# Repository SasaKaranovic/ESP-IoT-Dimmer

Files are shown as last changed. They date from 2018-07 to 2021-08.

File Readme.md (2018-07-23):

# ESP IoT Dimmer

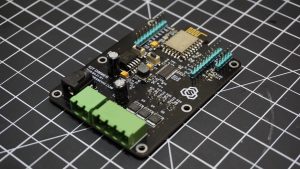
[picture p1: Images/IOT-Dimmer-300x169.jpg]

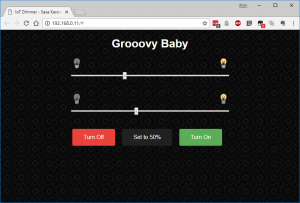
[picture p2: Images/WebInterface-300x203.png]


Making a IoT LED dimmer that you can control through your PC, your mobile, tablet or any other device connected to the network is super simple, and I'm going to show you how.

In this project I'm making a three channel LED dimmer that you can use to dim single RGB LED strip or dim three separate LED channels. I want to be able to control lights above my desk and also mix warm white and cool white strip to give me more flexibility over lighting while I'm working, taking pictures or watching movies.

This is going to be a very short and very simple project that if you follow steps below, you can build it in an hour (excluding lead time for components).

[Project home page](https://sasakaranovic.com/projects/iot-led-dimmer/)

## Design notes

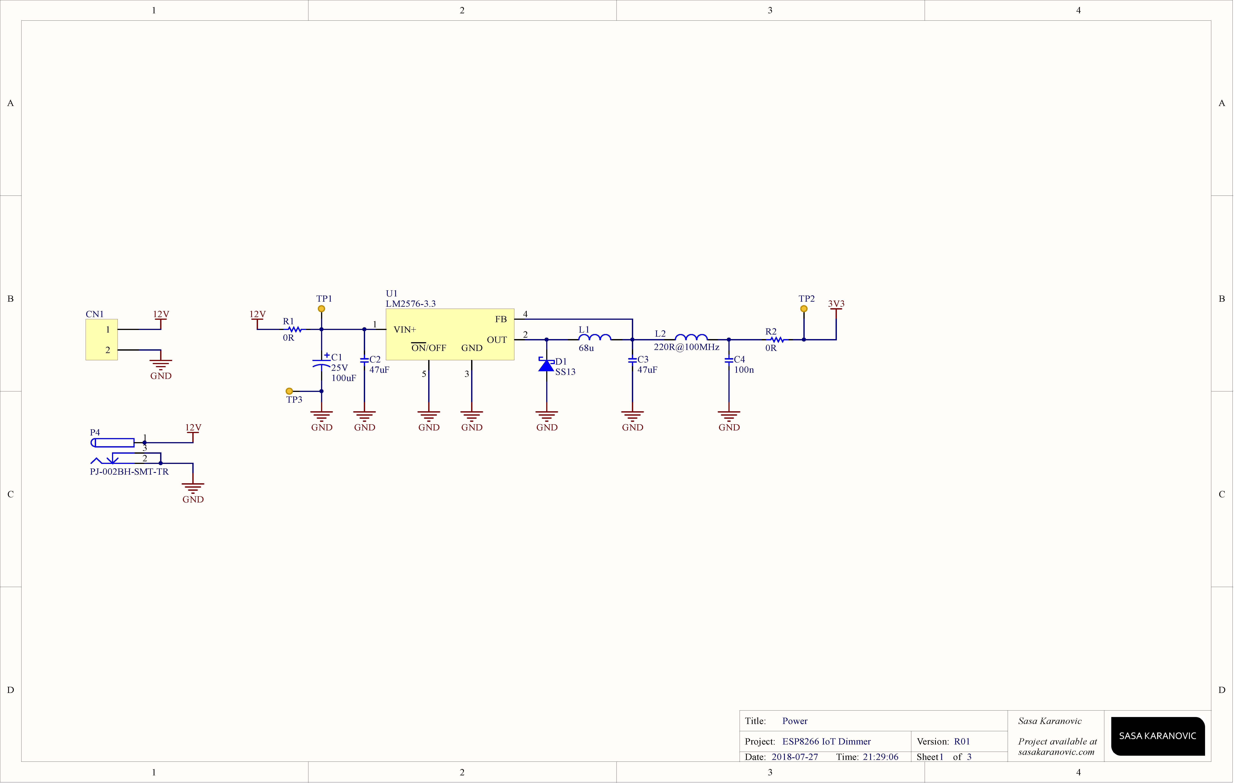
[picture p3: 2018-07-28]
Schematic/IoT Dimmer Schematic_Page_3.jpg

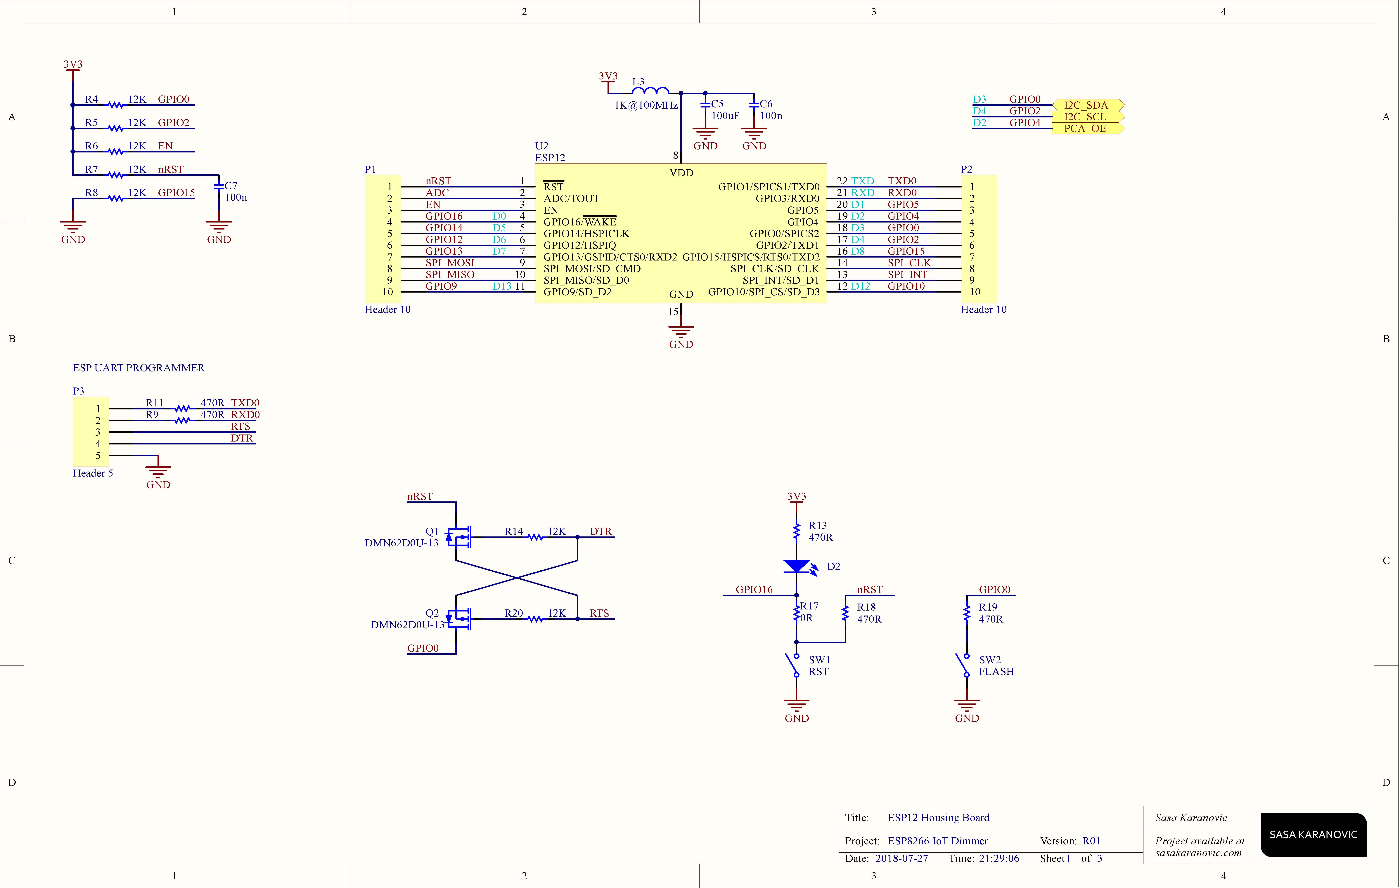
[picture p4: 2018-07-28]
Schematic/IoT Dimmer Schematic_Page_2.jpg

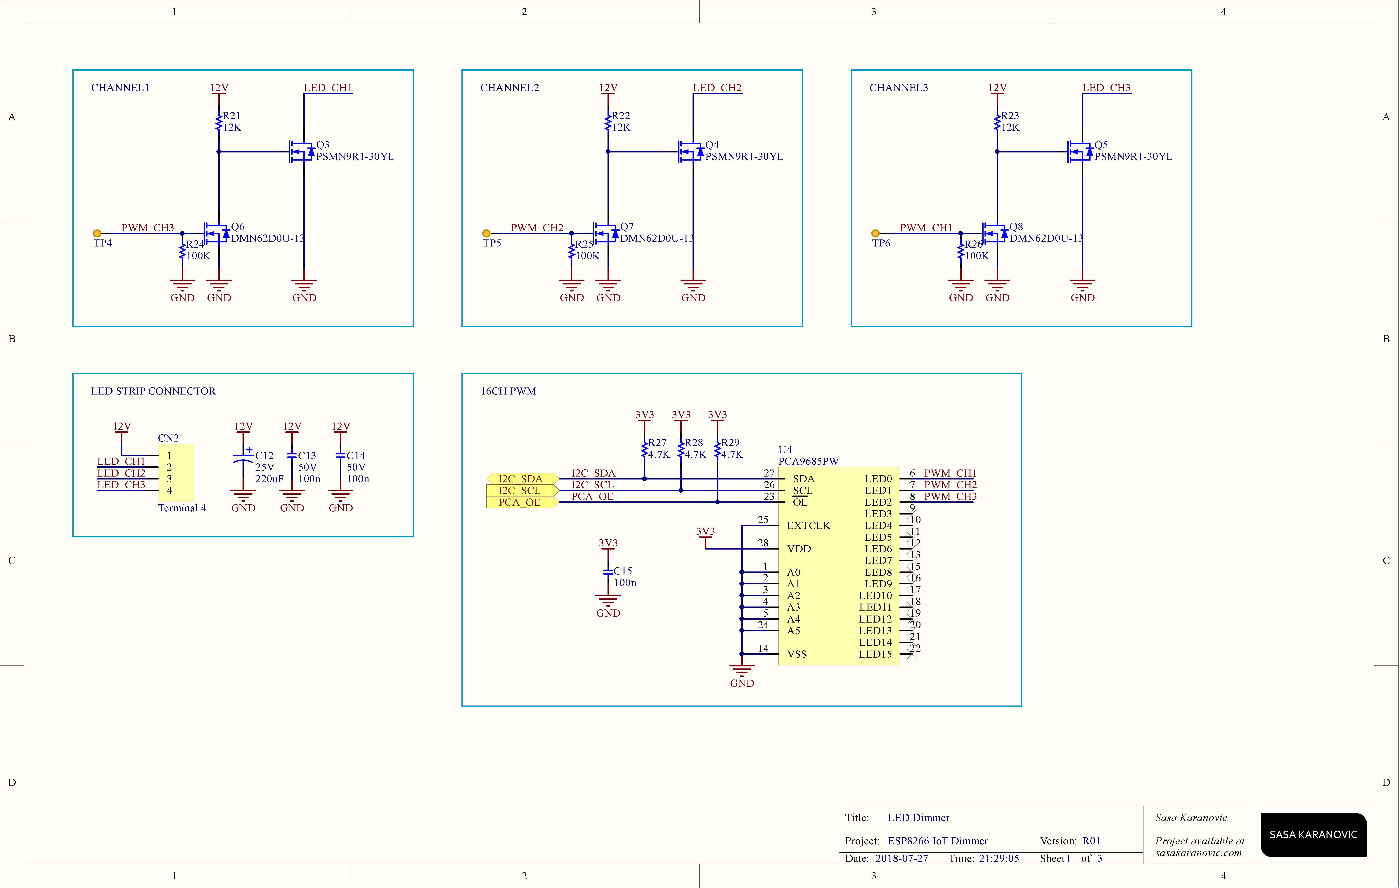
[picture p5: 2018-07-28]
Schematic/IoT Dimmer Schematic_Page_1.jpg

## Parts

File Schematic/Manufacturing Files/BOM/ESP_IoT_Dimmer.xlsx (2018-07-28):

Designator | Description | Manufacturer | Manufacturer Part Number | Quantity
C1 | CAP ALUM 100UF 20% 25V RADIAL | Nichicon | UHE1E101MED | 1
C2, C3 | CAP TANT POLY47UF 20% 16V 1210 | AVX Corporation | TCNT476M016R0200A | 2
C4, C6, C7, C13, C14, C15 | Capacitor | AVX Corporation | 06035C104KAT2A | 6
C5 | Capacitor | AVX Corporation | TAJB107M006RNJ | 1
C12, R9, R11, R13, R18, R19 | Polarized Capacitor (Axial), Resistor, Resistor, Resistor, Resistor, Resistor | Yageo | AC0603FR-07470RL | 6
CN1 | TERM BLOCK PCB 2POS 5.0MM GREEN | Phoenix Contact | 1935161 | 1
CN2 | TERM BLOCK PCB 4POS 5.0MM GREEN | Phoenix Contact | 1935187 | 1
D1 | DIODE SCHOTTKY 30V 1A SMA | ON Semiconductor | SS13 | 1
D2 | Typical RED GaAs LED | Lite-On Inc. | LTST-C193KRKT-5A | 1
L1 | FIXED IND 68UH 1A 289 MOHM SMD | Laird-Signal Integrity Products | TYS6045680M-10 | 1
L2 | FERRITE BEAD 220 OHM 0603 1LN | Murata Electronics North America | BLM18KG221SN1D | 1
L3 | FERRITE BEAD 1 KOHM 0603 1LN | TDK Corporation | MPZ1608S102ATA00 | 1
P1, P2, SW1, SW2 | Header, 10-Pin, Header, 10-Pin, Switch, Switch | Harwin Inc. | M20-9991046 | 4
P3 | SIL VERTICAL PC TAIL PIN HEADER | Harwin Inc. | M20-9990546 | 1
P4 | CONN PWR JACK 2.5X5.5MM SOLDER | CUI Inc. | PJ-002BH-SMT-TR | 1
Q1, Q2, Q6, Q7, Q8 | MOSFET N-CH 60V 0.38A | Diodes Incorporated | DMN62D0U-13 | 5
Q3, Q4, Q5 | MOSFET N-CH 30V 37A LFPAK | Nexperia USA Inc. | PSMN011-30YLC,115 | 3
R1, R2, R17 | Resistor | Yageo | RC0603JR-070RL | 3
R4, R5, R6, R7, R8, R14, R20, R21, R22, R23 | Resistor | Yageo | RT0603FRE0712KL | 10
R24, R25, R26 | Resistor | Yageo | RT0603BRD07100KL | 3
R27, R28, R29 | Resistor | Yageo | RT0603FRE074K7L | 3
U1 | Switching mode regulator [ 3v3, 5v, 12v and ADJ ] | Microchip Technology | LM2576-3.3WU | 1
U2 | ESP8266 SMT Module - ESP-12S | Seeed Technology Co., Ltd | 317060015 | 1
U4 | IC LED DRIVER RGBA 28-TSSOP | NXP USA Inc. | PCA9685PW,118 | 1
* Note
Manufacturer Part Number is for your reference only. I already had most of the components in stock so I used the ones I have handy. You may also replace any component with the one you have laying around.

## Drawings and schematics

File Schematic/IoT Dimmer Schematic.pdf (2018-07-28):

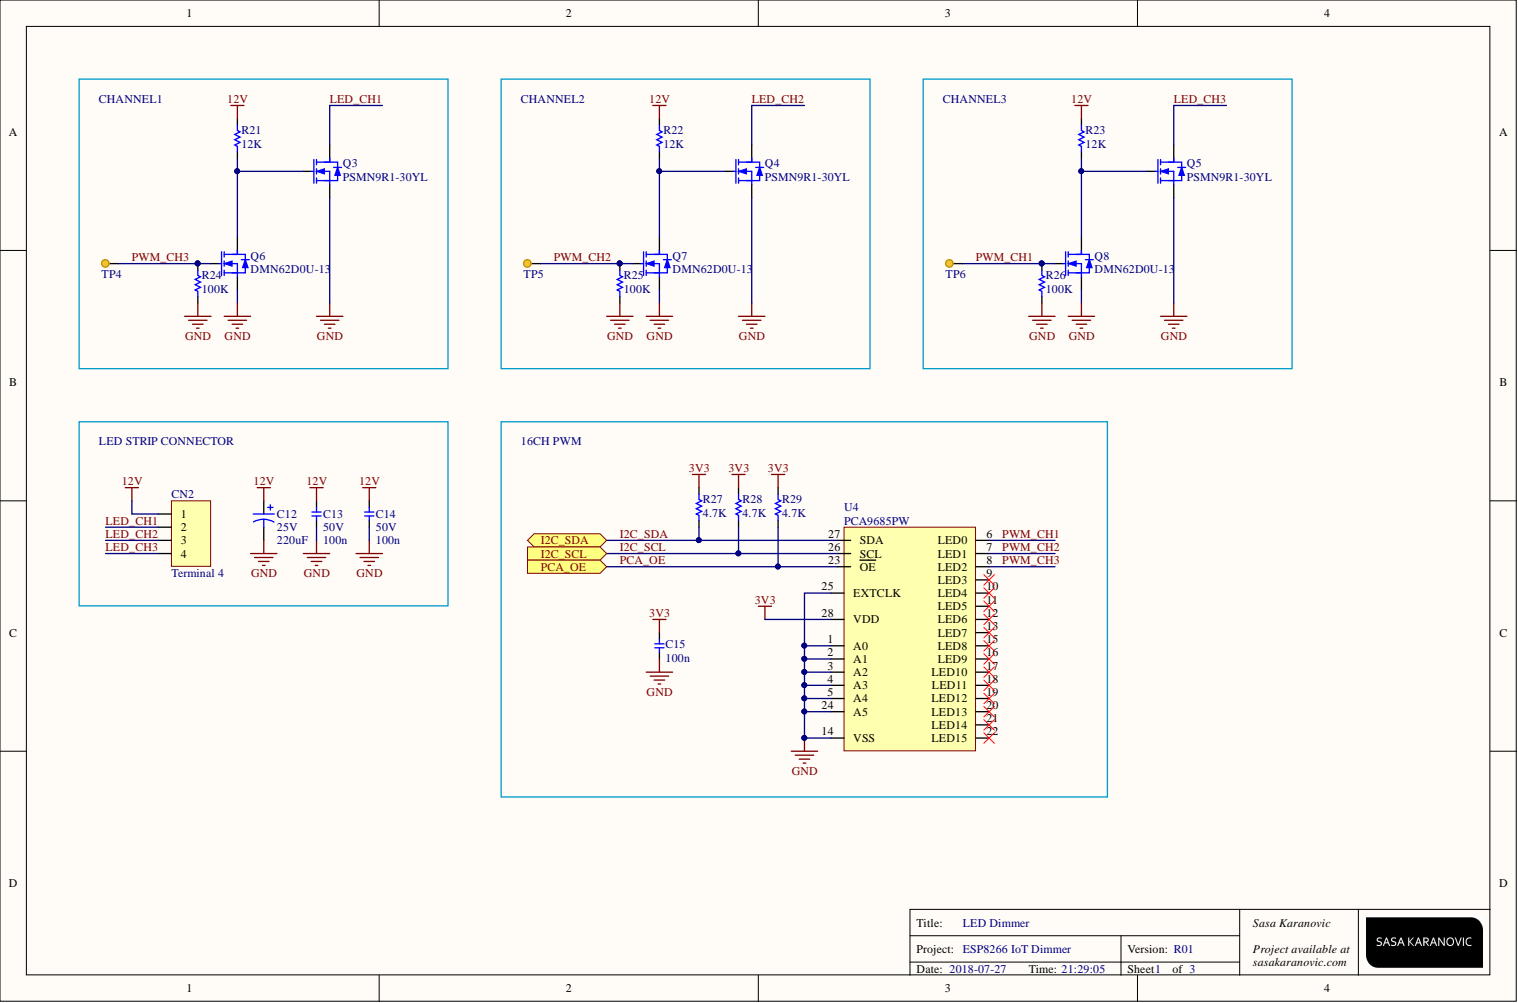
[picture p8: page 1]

VDD 28

A0 1
A1 2
A2 3
A3 4
A4 5
A5 24

VSS 14

Title: LED Dimmer | Sasa Karanovic Project available at sasakaranovic.com

Project: ESP8266 IoT Dimmer | Version: R01
Date: Time: 2018-07-27 21:29:05 | Sheet of 1 3

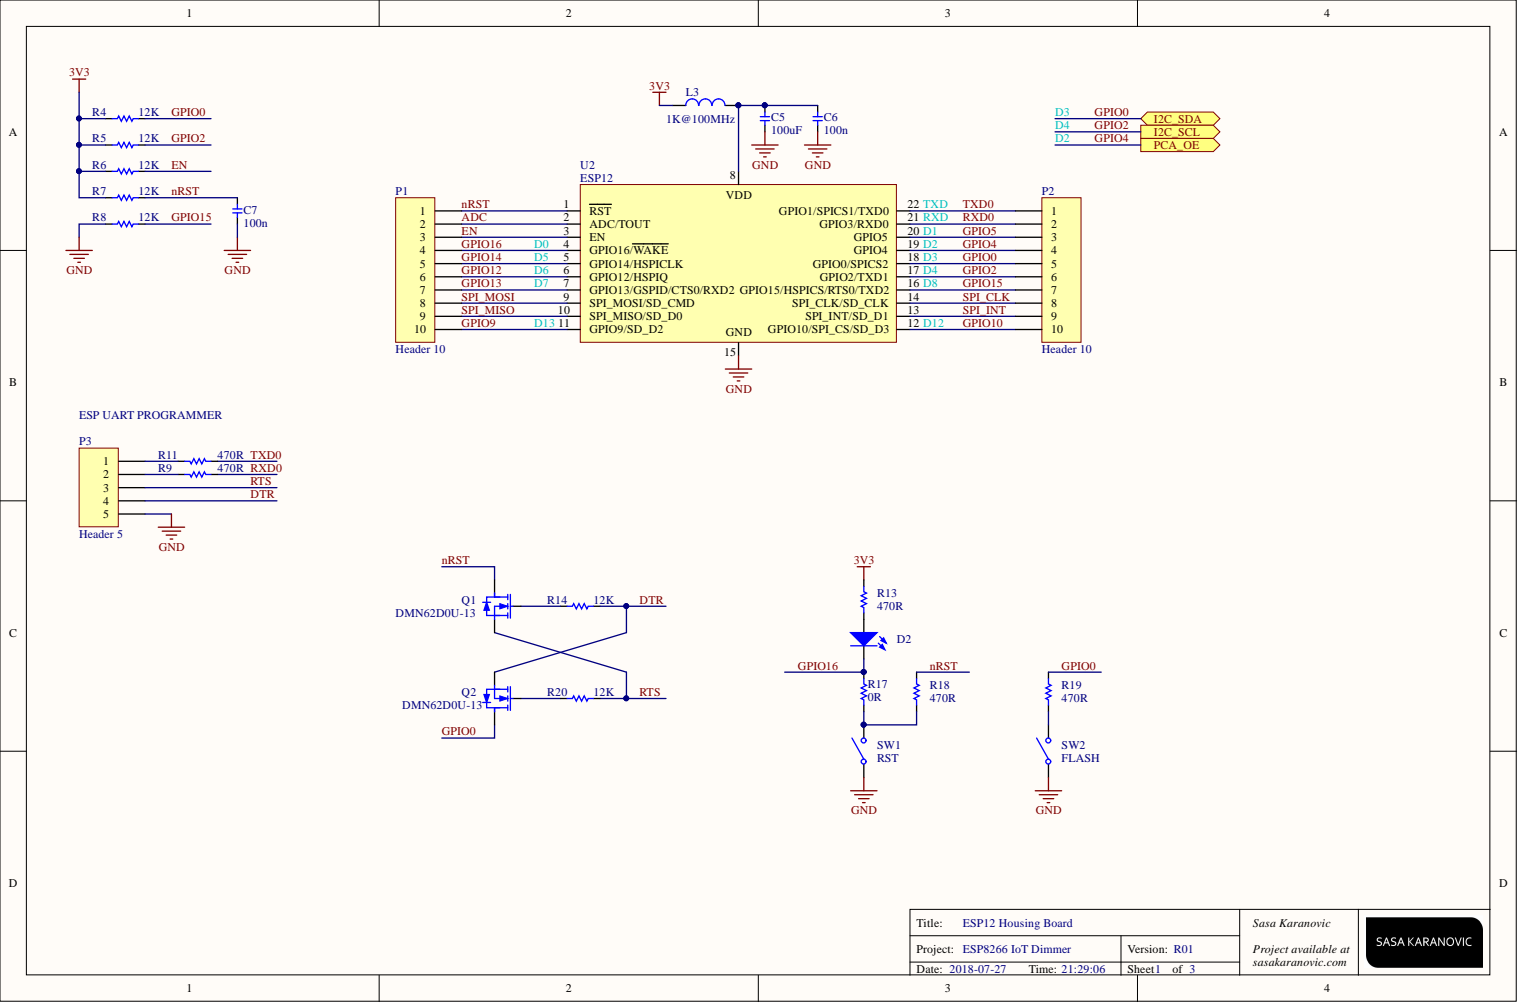
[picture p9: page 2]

GPIO16 D0 | GPIO16/WAKE 4 | D2 GPIO4
GPIO14 D5 | GPIO14/HSPICLK 5 | D3 GPIO0
GPIO12 D6 | GPIO12/HSPIQ 6 | D4 GPIO2
GPIO13 D7 | GPIO13/GSPID/CTS0/RXD2 7 | D8 GPIO15
SPI_MOSI | SPI_MOSI/SD_CMD 9 | SPI_CLK

Title: ESP12 Housing Board | Sasa Karanovic Project available at sasakaranovic.com

Project: ESP8266 IoT Dimmer | Version: R01
Date: Time: 2018-07-27 21:29:06 | Sheet of 1 3

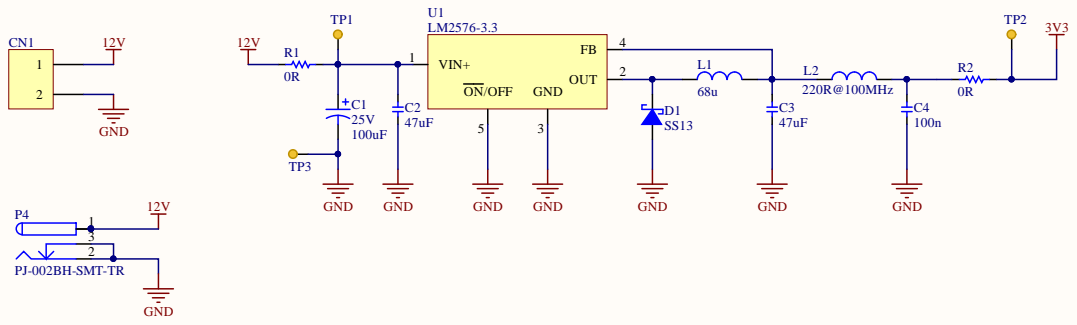
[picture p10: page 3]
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

Project : ESP8 6 Io T D immer | Vers i o n : R0
Date: 8-0 7-2 T ime: : : | Sheet o f

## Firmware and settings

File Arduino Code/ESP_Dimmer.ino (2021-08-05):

#include <ESP8266WiFi.h>
#include <ESP8266WiFiMulti.h>
#include <WebSocketsServer.h>
#include <Hash.h>
#include <String.h>
#include <ESP8266WebServer.h>
#include <ESP8266mDNS.h>
#include <Wire.h>
#include <Adafruit_PWMServoDriver.h>
// called this way, it uses the default address 0x40
Adafruit_PWMServoDriver pwm = Adafruit_PWMServoDriver();

// WiFi Configuration (hard-coded at the moment)
// static const char ssid[] = "__Your-WiFi-SSID__";
// static const char password[] = "__Your-WiFi-Password-Here__";

// mDNS hostname for this device
// You should be able to call http://dimmer.iot
static const char dns_hostname[] = "dimmer";

// Channel Configuration (pins)
#define CH1_PIN         0
#define CH2_PIN         1
#define CH3_PIN         2
#define EN_PIN          4

#define DEBUG_BUILD 0

// Global variables
volatile uint32_t milis_update = 0;
volatile uint32_t debug_update = 0;
volatile uint16_t ch1_target   = 0;  // Channel target value (not used yet)
volatile uint16_t ch2_target   = 0;  // Channel target value (not used yet)
volatile uint16_t ch3_target   = 0;  // Channel target value (not used yet)

// GPIO#0 is for Adafruit ESP8266 HUZZAH board. Your board LED might be on 13.
const int LEDPIN = 0;

// Static function definitions
static void writeLED(uint8_t channel, uint16_t value);

// Initialize classes
MDNSResponder mdns;
ESP8266WiFiMulti WiFiMulti;
ESP8266WebServer server(80);
WebSocketsServer webSocket = WebSocketsServer(81);

// -- BEGIN Index.html
static const char PROGMEM INDEX_HTML[] = R"rawliteral(
<!DOCTYPE html>
<html>
<head>
<meta name = "viewport" content = "width = device-width, initial-scale = 1.0, maximum-scale = 1.0, user-scalable=0">
<title>Sasa's IoT Dimmer - Sasa Karanovic</title>
<style>
body { background: #262830 url('http://sasakaranovic.com/iotdimmer/bg.png') repeat; font-family: Arial, Helvetica, Sans-Serif; Color: #fffff9; }
#container { width: 80%; max-width: 450px; margin: auto; }
.bulb { display: block; clear: none; width: 32px; height: 32px; padding-bottom: 0.5em; background-attachment: fixed; background-position: center; background-repeat: no-repeat; }
.bulbOn { background: transparent url('http://sasakaranovic.com/iotdimmer/bulbON.png') top left no-repeat; float: right; }
.bulbOff{ background: transparent url('http://sasakaranovic.com/iotdimmer/bulbOFF.png') top left no-repeat; float: left; }
h1 {  display: block; font-size: 2em; margin-top: 0.67em; margin-bottom: 0.67em; margin-left: 0; margin-right: 0; font-weight: bold; text-align: center; }
.slidecontainer {width: 100%; }
.slider {width: 100%; margin: 0 0 3em 0; }
  .buttonOff { background-color: #f44336; }
  .buttonOn{ background-color: #4CAF50; }
  a { 
  background-color: #212121;
    border: none;
    color: white;
    padding: 15px 32px;
  margin-right: 1em;
    text-align: center;
    text-decoration: none;
    display: inline-block;
    font-size: 16px;
  border-radius: 4px;
  }
</style>
<script>
var websock;
function start() {
websock = new WebSocket('ws://' + window.location.hostname + ':81/');
websock.onopen = function(evt) { console.log('websock open'); };
websock.onclose = function(evt) { console.log('websock close'); };
websock.onerror = function(evt) { console.log(evt); };
websock.onmessage = function(evt) {
console.log(evt);
var ch1 = document.getElementById('ch1');
var ch2 = document.getElementById('ch2');
var ch3 = document.getElementById('ch3');
var ch_values = JSON.parse(evt.data);
ch1.value = ch_values.ch1;
ch2.value = ch_values.ch2;
ch3.value = ch_values.ch3;
};
}
function setAll(val) {
var dat = 'ch0:'+ val
websock.send(dat);
}
function updateSlider(e) {
var dat = e.id +':'+ e.value
websock.send(dat);
}
</script>
</head>
<body onload="javascript:start();">
<div id="container">
<h1>Grooovy Baby</h1>
<div class="slidecontainer">
<div class="bulb bulbOn"></div>
<div class="bulb bulbOff"></div>
<input id="ch1" type="range" min="1" max="4095" value="0" class="slider" onchange="updateSlider(this)">
</div>
<div class="slidecontainer">
<div class="bulb bulbOn"></div>
<div class="bulb bulbOff"></div>
<input id="ch2" type="range" min="1" max="4095" value="0" class="slider" onchange="updateSlider(this)">
</div>
<div class="slidecontainer" style="display:none; visibility: hidden">
<div class="bulb bulbOn"></div>
<div class="bulb bulbOff"></div>
<input id="ch3" type="range" min="1" max="4095" value="0" class="slider" onchange="updateSlider(this)">
</div>
<div class="slidecontainer" style="text-align: center">
<a href="#" class="buttonOff" onClick="setAll(1)">Turn Off</a> <a href="#" onClick="setAll(2049)">Set to 50%</a> <a href="#" class="buttonOn"  onClick="setAll(4096)">Turn On</a>
</div>
</div>
</body>
</html>
)rawliteral";
// -- END Index.html

// WebSocket Event Handler
void webSocketEvent(uint8_t num, WStype_t type, uint8_t * payload, size_t length)
{
  char buffer[40] = {0};
  String content((char*)payload);
  #if DEBUG_BUILD
  Serial.printf("webSocketEvent(%d, %d, ...)\r\n", num, type);
  #endif
  switch(type) {
    case WStype_DISCONNECTED:
      Serial.printf("[%u] Disconnected!\r\n", num);
      break;
    // --When new connection is established
    case WStype_CONNECTED:
      {
        IPAddress ip = webSocket.remoteIP(num);
        sprintf(buffer, "{\"ch1\":%d,\"ch2\":%d,\"ch3\":%d}", ch1_target,  ch2_target,  ch3_target);
        #if DEBUG_BUILD
        Serial.printf("[%u] Connected from %d.%d.%d.%d url: %s\r\n", num, ip[0], ip[1], ip[2], ip[3], payload);
        #endif
        // Send the current LED status
        webSocket.sendTXT(num, buffer, strlen(buffer));
      }
      break;
    // -- This is what we get from WebSocket
    case WStype_TEXT:
      #if DEBUG_BUILD
      Serial.printf("[%u] get Text: %s\r\n", num, payload);
      #endif

      // Check if data is for Channel1
      if(content.indexOf("ch1:") >= 0)
      {
        content.remove(0,4);  // Remove first 3 characters
        #if DEBUG_BUILD
        Serial.print("Channel 1 value: ");
        Serial.println(content);
        #endif
        writeLED(1, content.toInt());
      }
      // Check if data is for Channel2
      else if(content.indexOf("ch2:") >= 0)
      {
        content.remove(0,4);  // Remove first 3 characters
        #if DEBUG_BUILD
        Serial.print("Channel 2 value: ");
        Serial.println(content);
        #endif
        writeLED(2, content.toInt());
      }
      // Check if data is for Channel3
      else if(content.indexOf("ch3:") >= 0)
      {
        content.remove(0,4);  // Remove first 3 characters
        #if DEBUG_BUILD
        Serial.print("Channel 3 value: ");
        Serial.println(content);
        #endif
        writeLED(3, content.toInt());
      }
      else if(content.indexOf("ch0:") >= 0)
      {
        content.remove(0,4);  // Remove first 3 characters
        #if DEBUG_BUILD
        Serial.print("Channel 3 value: ");
        Serial.println(content);
        #endif
        writeLED(0, content.toInt());
      }
      else
      {
        Serial.println("Unknown command?!");
      }

      // send data to all connected clients
      sprintf(buffer, "{\"ch1\":%d,\"ch2\":%d,\"ch3\":%d}", ch1_target,  ch2_target,  ch3_target);
      webSocket.broadcastTXT(buffer, strlen(buffer));
      break;
    // -- Binary?
    case WStype_BIN:
      #if DEBUG_BUILD
      Serial.printf("[%u] get binary length: %u\r\n", num, length);
      #endif
      hexdump(payload, length);

      // echo data back to browser
      webSocket.sendBIN(num, payload, length);
      break;
    default:
      Serial.printf("Invalid WStype [%d]\r\n", type);
      break;
  }
}

// Function handler when http root is requested
void handleRoot()
{
  server.send_P(200, "text/html", INDEX_HTML);
}

// Function handler for invalid (404) page
void handleNotFound()
{
  String message = "File Not Found\n\n";
  message += "URI: ";
  message += server.uri();
  message += "\nMethod: ";
  message += (server.method() == HTTP_GET)?"GET":"POST";
  message += "\nArguments: ";
  message += server.args();
  message += "\n";
  for (uint8_t i=0; i<server.args(); i++){
    message += " " + server.argName(i) + ": " + server.arg(i) + "\n";
  }
  server.send(404, "text/plain", message);
}

// Update Channel Value
static void writeLED(uint8_t channel, uint16_t value)
{
  #if DEBUG_BUILD
  Serial.printf("Channel%d=%d\n", channel, value);
  #endif

  if(value > 4095)
  {
    #if DEBUG_BUILD
    Serial.printf("Invalid value passed for channel %d=%d\n!", channel, value);
    #endif
    value = 4095;
  }

  //Determine which channel needs to be updated
  switch(channel)
  {
    case 0:
      ch1_target = value;
      pwm.setPWM(CH1_PIN, value, 0);

      ch2_target = value;
      pwm.setPWM(CH2_PIN, value, 0);

      ch3_target = value;
      pwm.setPWM(CH3_PIN, value, 0);

    break;

    case 1:
    if(ch1_target != value)
    {
      ch1_target = value;
      pwm.setPWM(CH1_PIN, value, 0);
    }
    break;

    case 2:
    if(ch2_target != value)
    {
      ch2_target = value;
      pwm.setPWM(CH2_PIN, value, 0);
    }
    break;

    case 3:
    if(ch3_target != value)
    {
      ch3_target = value;
      pwm.setPWM(CH3_PIN, value, 0);
    }
    break;

    default:
    Serial.printf("Invalid channel selected (%d)! [Valid channels are 1-3]\r\n", channel);
    break;
  }
}

// SetUp ESP8266
void setup()
{
  pinMode(EN_PIN, OUTPUT);
  digitalWrite(EN_PIN, HIGH);
  
  Serial.begin(115200);

  //Serial.setDebugOutput(true);

  Serial.println();
  Serial.println();
  Serial.println();

  for(uint8_t t = 4; t > 0; t--) {
    Serial.printf("[SETUP] BOOT WAIT %d...\r\n", t);
    Serial.flush();
    delay(1000);
  }
  
  WiFi.mode(WIFI_STA);
  WiFiMulti.addAP(ssid, password);

  while(WiFiMulti.run() != WL_CONNECTED) {
    Serial.print(".");
    delay(1000);
  }

  Serial.println("");
  Serial.print("Connected to ");
  Serial.println(ssid);
  Serial.print("IP address: ");
  Serial.println(WiFi.localIP());

  // Setup mDNS to allow accessing this unit through http://DNS_NAME.local
  if (mdns.begin(dns_hostname, WiFi.localIP())) {
    Serial.println("MDNS responder started");
    mdns.addService("http", "tcp", 80);
    mdns.addService("ws", "tcp", 81);
  }
  else {
    Serial.println("MDNS.begin failed");
  }
  Serial.printf("Connect to http://%s.local or http://", dns_hostname);
  Serial.println(WiFi.localIP());

  server.onNotFound(handleNotFound);
  server.on("/", handleRoot);
  server.on("/get_status", api_get_status);
  server.on("/set_channel", handleGenericArgs);


  server.begin();

  webSocket.begin();
  webSocket.onEvent(webSocketEvent);

  Serial.println("Setting up I2C on D3 and D4");
  Wire.begin(D3, D4); /* join i2c bus with SDA=D1 and SCL=D2 of NodeMCU */
  
  Serial.println("Turning on PWM");
  pwm.begin();
  pwm.setPWMFreq(1600);  // This is the maximum PWM frequency

  Serial.println("Setting CH0-2 to OFF.");
  pwm.setPWM(CH1_PIN, 1, 4096);
  pwm.setPWM(CH2_PIN, 1, 4096);
  pwm.setPWM(CH3_PIN, 1, 4096);
  digitalWrite(EN_PIN, LOW);

}

void api_get_status(void)
{
  Serial.println("api_get_status");
  char buff[200] = {0};

  sprintf(buff, "{\"ch1\":%d, \"ch2\":%d, \"ch3\":%d}", ch1_target, ch2_target, ch3_target);
  server.send(404, "text/plain", buff);
}


void handleGenericArgs() { //Handler
  Serial.println("handleGenericArgs");
      int32_t api_ch0 = -1;
      int32_t api_ch1 = -1;
      int32_t api_ch2 = -1;
      int32_t api_ch3 = -1;

  for (int i = 0; i < server.args(); i++) {
    if( strncmp(server.argName(i).c_str(), "ch0", 3) == 0) {  api_ch0 = server.arg(i).toInt(); }
    if( strncmp(server.argName(i).c_str(), "ch1", 3) == 0) {  api_ch1 = server.arg(i).toInt(); }
    if( strncmp(server.argName(i).c_str(), "ch2", 3) == 0) {  api_ch2 = server.arg(i).toInt(); }
    if( strncmp(server.argName(i).c_str(), "ch3", 3) == 0) {  api_ch3 = server.arg(i).toInt(); }

    if(api_ch0 >= 0) { writeLED(0, api_ch0); }
    if(api_ch1 >= 0) { writeLED(1, api_ch1); }
    if(api_ch2 >= 0) { writeLED(2, api_ch2); }
    if(api_ch3 >= 0) { writeLED(3, api_ch3); }

  } 

    // send data to all connected clients
    char buffer[100] = {0};
    sprintf(buffer, "{\"ch1\":%d,\"ch2\":%d,\"ch3\":%d}", ch1_target,  ch2_target,  ch3_target);
    webSocket.broadcastTXT(buffer, strlen(buffer));

  server.send(200, "text/plain", buffer);       //Response to the HTTP request

}

// Main()
void loop()
{
  webSocket.loop();
  server.handleClient();
}

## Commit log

2018-07-23 IoT Dimmer Initial commit
    [00_TOP.SchDoc, 01_Power.SchDoc, 02_ESP12.SchDoc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]
2018-07-28 Adding BoM. Updating Schematic. Updating Altium source files.
    [01_Power.SchDoc, 02_ESP12.SchDoc, 03_Dimmer.SchDoc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]
2018-07-28 BoM note
    [ESP_IoT_Dimmer.xlsx]
